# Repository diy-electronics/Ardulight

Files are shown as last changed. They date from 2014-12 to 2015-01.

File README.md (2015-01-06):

Ardulight
=========

Ardu(ino)(Ambi)light: An arduino based ambilight controller for WS2801 based digital rgb led pixels.

Example-Video:<br />
<a href="http://www.youtube.com/watch?feature=player_embedded&v=HK8IQF8XRPc
" target="_blank">Example</a>

Images
------

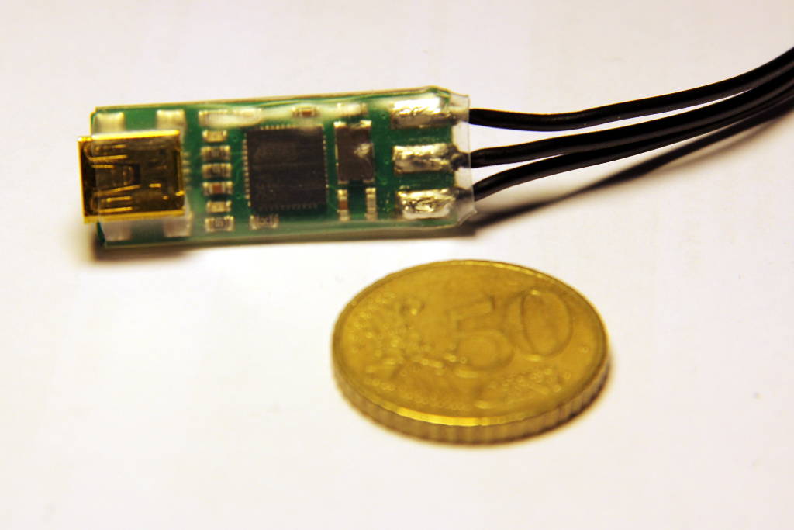
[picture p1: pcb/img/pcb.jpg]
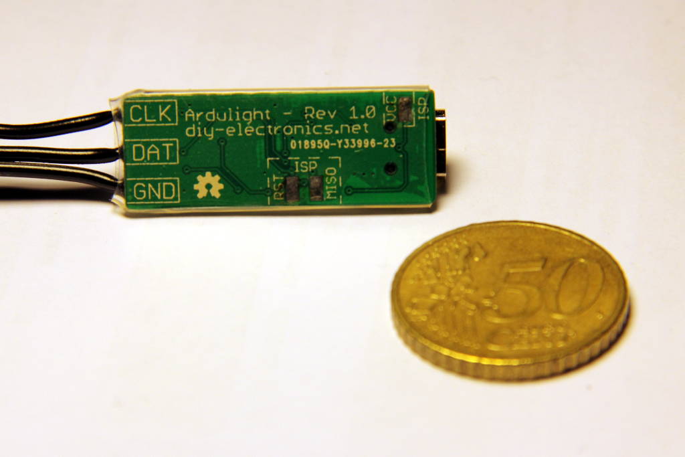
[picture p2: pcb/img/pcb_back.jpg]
&nbsp;&nbsp;&nbsp;

Assembly
--------

Assembly instructions including a BOM (bill of materials) can be found [here](../master/pcb).<br />
The pcb has to be soldered by hot air or by reflow due to the qfp package of the atmega32u4.

Wiring
------

For a detailed wiring guide look [here](https://learn.adafruit.com/adalight-diy-ambient-tv-lighting/wiring-1).<br />
The LED-Strip has to be powered from an external power source, using e.g. a connector like [this](https://www.adafruit.com/products/368).<br />
You only have to connect GND, CLK (SCK) and DAT (MOSI).  

Firmware
--------

The firmware can be found [here](../master/firmware/firmware.pde)<br />
You can flash this firmware using an isp-programmer.<br />
Alternatively you can first flash the arduino leonardo bootloader with an isp-programmer and then flash the firmware directly over usb since the ambilight controller is compatible with the arduino leonardo.

Software
--------

The ambilight controller works with [Prismatik from woodenshark](https://github.com/woodenshark/Lightpack/releases/latest) (Alternative download [here](http://lightpack.tv/downloads)).

To fix the systems device name and permissions for Ardulight on linux systems, you can add [the udev rule](98-ardulight.rules) to `/etc/udev/rules.d/`. The device name is then `/dev/ttyARDULIGHT` and is owned by `users (mode 0666)`.

License
-------

<br />This work is licensed under a <a rel="license" href="http://creativecommons.org/licenses/by-sa/4.0/">Creative Commons Attribution-ShareAlike 4.0 International License</a>.<br />
The firmware is licensed under a GNU Lesser General Public, see <http://www.gnu.org/licenses/>.<br />

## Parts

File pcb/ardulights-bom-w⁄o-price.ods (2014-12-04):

Qty | Value | Package | Parts | Description | Distributor/PN
1 |  | QFN-44 | U1 | IC MCU 8BIT 32KB FLASH 44QFN | Digikey: ATMEGA32U4-MU-ND
1 |  | SMD | JP1 | CONN MINI USB RCPT RA TYPE B SMD | Digikey: 151-1206-1-ND
1 | 16M | SMD | Y1 | CRYSTAL 16MHZ 8PF SMD | Digikey: 644-1194-1-ND
2 | 18p | 0603 | C5, C6 | CAP CER 18PF 50V 5% C0G 0603 | Digikey: 445-1272-1-ND
3 | 0.1u | 0603 | C1, C2, C3 | CAP CER 0.1UF 25V 10% X7R 0603 | Digikey: 445-1316-1-ND
1 | 10k | 0603 | R2 | RES 10K OHM 1/10W 1% 0603 | Digikey: A106048CT-ND
2 | 22R | 0603 | R3, R4 | RES 22 OHM 1/10W 1% 0603 | Digikey: RMCF0603FT22R0CT-ND
1 | 1u | 0603 | C4 | CAP CER 1UF 50V 10% X5R 0603 | Digikey: 445-7468-1-ND
1 | BLUE | 0603 | PWR | LED 468NM BLUE CLEAR 0603 SMD | Digikey: 160-1647-1-ND
1 | YELLOW | 0603 | RX | LED YELLOW CLEAR THIN 0603 SMD | Digikey: 160-1448-1-ND
1 | 150R | 0603 | R5 | RES 150 OHM 1/10W 1% 0603 SMD | Digikey: RHM150CFCT-ND
1 | 82R | 0603 | R1 | RES 82 OHM 1/10W 1% 0603 SMD | Digikey: RHM82CFCT-ND
---- optional ----
1 |  |  |  | CBL USB A-MNI B CON 3' 28/28 AWG | Digikey: Q362-ND
1 |  |  |  | 4-pin JST SM Plug + Receptacle Cable Set | EXP-TECH: EXP-R15-235
1 |  |  |  | Female DC Power adapter - 2.1mm jack to screw terminal block | EXP-TECH: EXP-R15-080

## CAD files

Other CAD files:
pcb/ardulight.skp

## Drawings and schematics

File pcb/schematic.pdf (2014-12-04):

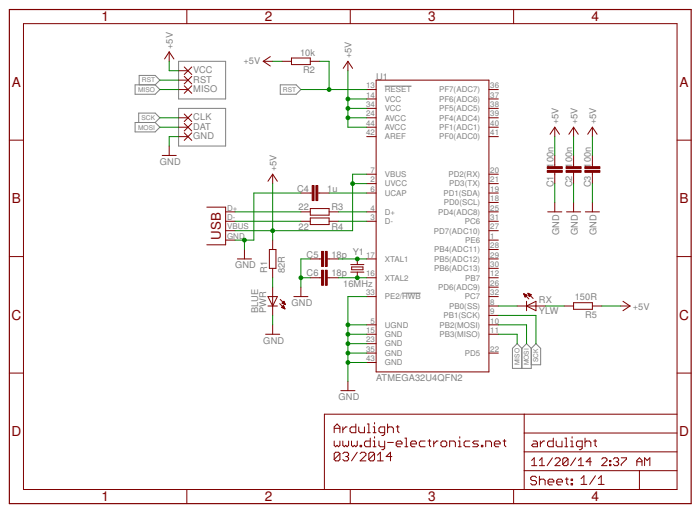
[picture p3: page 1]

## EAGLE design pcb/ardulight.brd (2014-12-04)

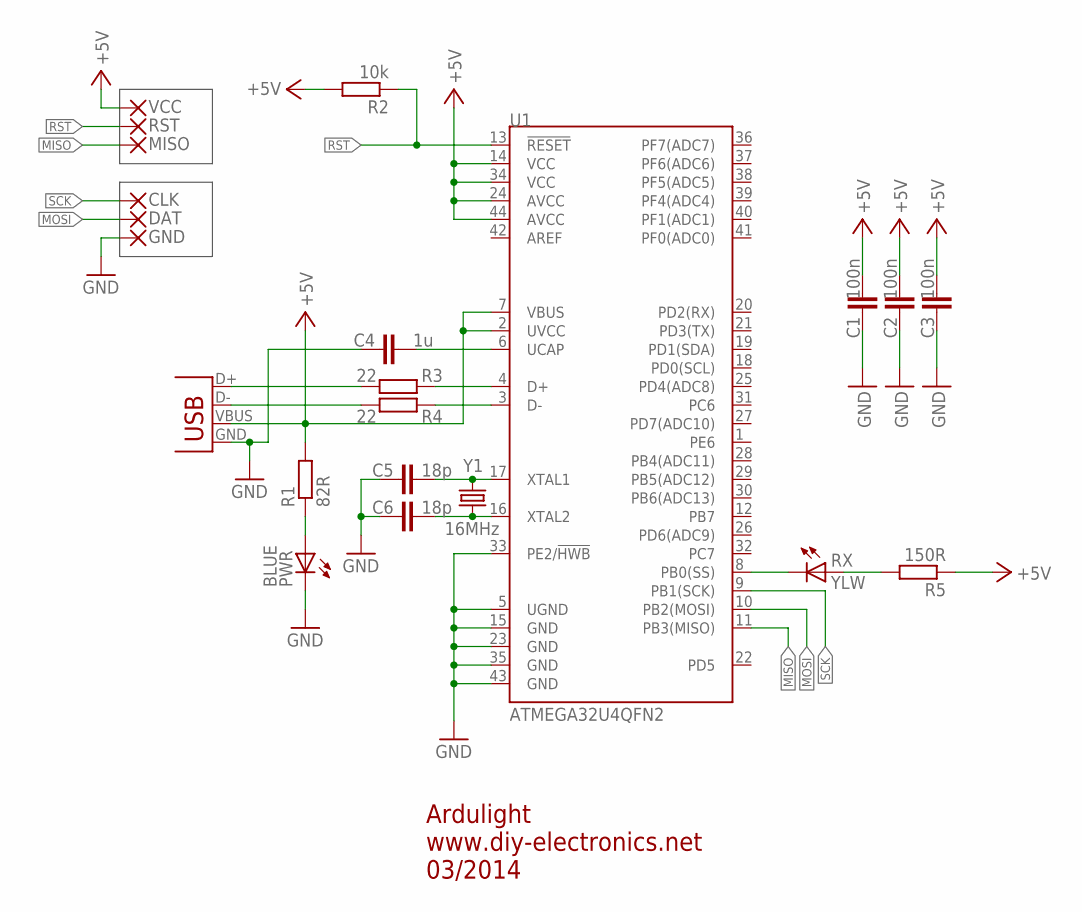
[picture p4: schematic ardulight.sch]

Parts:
C1, C2, C3: 100n; C0603
C4: 1u; C0603
C5, C6: 18p; C0603
CLK: SMD5; SMD2,54-5,08
DAT: SMD5; SMD2,54-5,08
GND: SMD5; SMD2,54-5,08
JP1: USBSMD; USB-MINIB
MISO: SMD2; SMD1,27-2,54
PWR: BLUE; CHIPLED_0603
R1: 82R; R0603
R2: 10k; R0603
R3, R4: 22; R0603
R5: 150R; R0603
RST: SMD2; SMD1,27-2,54
RX: YLW; CHIPLED_0603
U1: ATMEGA32U4QFN2; SPARKFUN-DIGITALIC_QFN-44-NOPAD
VCC: SMD2; SMD1,27-2,54
Y1: 16MHz; CRYSTAL-SMD-5X3

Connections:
+5V: C1.2, C2.2, C3.2, JP1.VBUS, R1.2, R2.2, R5.1, U1.2 (UVCC), U1.7 (VBUS), U1.14 (VCC), U1.24 (AVCC), U1.34 (VCC), U1.44 (AVCC), VCC.1
GND: C1.1, C2.1, C3.1, C4.1, C5.1, C6.1, GND.1, JP1.GND, PWR.C, U1.5 (UGND), U1.15 (GND), U1.23 (GND), U1.33 (PE2/!HWB), U1.35 (GND), U1.43 (GND)
MISO: MISO.1, U1.11 (PB3(MISO))
MOSI: DAT.1, U1.10 (PB2(MOSI))
unnamed: C5.2, U1.17 (XTAL1), Y1.3 (2)
unnamed: C6.2, U1.16 (XTAL2), Y1.1
unnamed: R3.1, U1.4 (D+)
unnamed: C4.2, U1.6 (UCAP)
unnamed: RX.C, U1.8 (PB0(SS))
unnamed: R4.1, U1.3 (D-)
unnamed: JP1.D+, R3.2
unnamed: JP1.D-, R4.2
unnamed: PWR.A, R1.1
unnamed: R5.2, RX.A
RST: R2.1, RST.1, U1.13 (!RESET)
SCK: CLK.1, U1.9 (PB1(SCK))

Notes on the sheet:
Ardulight
www.diy-electronics.net
03/2014

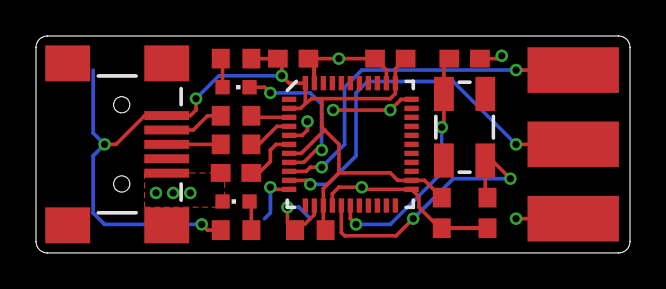
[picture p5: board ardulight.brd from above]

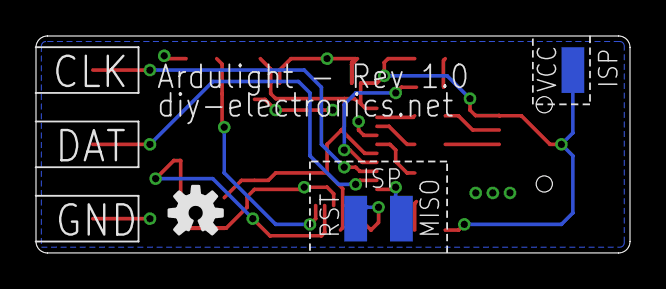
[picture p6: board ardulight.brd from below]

Board: 2 copper layers, 33.0 x 12.1 mm, 23 parts (4 on the bottom side), 16 nets.

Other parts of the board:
U$1: OSHW-LOGO-S

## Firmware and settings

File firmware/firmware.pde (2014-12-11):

//   This file is part of Adalight.

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
#include <SPI.h>

// A 'magic word' (along with LED count & checksum) precedes each block
// of LED data; this assists the microcontroller in syncing up with the
// host-side software and properly issuing the latch (host I/O is
// likely buffered, making usleep() unreliable for latch).  You may see
// an initial glitchy frame or two until the two come into alignment.
// The magic word can be whatever sequence you like, but each character
// should be unique, and frequent pixel values like 0 and 255 are
// avoided -- fewer false positives.  The host software will need to
// generate a compatible header: immediately following the magic word
// are three bytes: a 16-bit count of the number of LEDs (high byte
// first) followed by a simple checksum value (high byte XOR low byte
// XOR 0x55).  LED data follows, 3 bytes per LED, in order R, G, B,
// where 0 = off and 255 = max brightness.

static const uint8_t magic[] = {'A','d','a'};
#define MAGICSIZE  sizeof(magic)
#define HEADERSIZE (MAGICSIZE + 3)

#define MODE_HEADER 0
#define MODE_HOLD   1
#define MODE_DATA   2

// If no serial data is received for a while, the LEDs are shut off
// automatically.  This avoids the annoying "stuck pixel" look when
// quitting LED display programs on the host computer.
static const unsigned long serialTimeout = 15000; // 15 seconds

void setup()
{
  // Dirty trick: the circular buffer for serial data is 256 bytes,
  // and the "in" and "out" indices are unsigned 8-bit types -- this
  // much simplifies the cases where in/out need to "wrap around" the
  // beginning/end of the buffer.  Otherwise there'd be a ton of bit-
  // masking and/or conditional code every time one of these indices
  // needs to change, slowing things down tremendously.
  uint8_t
    buffer[256],
    indexIn       = 0,
    indexOut      = 0,
    mode          = MODE_HEADER,
    hi, lo, chk, i, spiFlag;
  int16_t
    bytesBuffered = 0,
    hold          = 0,
    c;
  int32_t
    bytesRemaining;
  unsigned long
    startTime,
    lastByteTime,
    lastAckTime,
    t;

  Serial.begin(115200); // Teensy/32u4 disregards baud rate; is OK!

  SPI.begin();
  SPI.setBitOrder(MSBFIRST);
  SPI.setDataMode(SPI_MODE0);
  SPI.setClockDivider(SPI_CLOCK_DIV16); // 1 MHz max, else flicker

  // Issue test pattern to LEDs on startup.  This helps verify that
  // wiring between the Arduino and LEDs is correct.  Not knowing the
  // actual number of LEDs connected, this sets all of them (well, up
  // to the first 25,000, so as not to be TOO time consuming) to red,
  // green, blue, then off.  Once you're confident everything is working
  // end-to-end, it's OK to comment this out and reprogram the Arduino.
  uint8_t testcolor[] = { 0, 0, 0, 255, 0, 0 };
  for(char n=3; n>=0; n--) {
    for(c=0; c<25000; c++) {
      for(i=0; i<3; i++) {
        for(SPDR = testcolor[n + i]; !(SPSR & _BV(SPIF)); );
      }
    }
    delay(1); // One millisecond pause = latch
  }

  Serial.print("Ada\n"); // Send ACK string to host

  startTime    = micros();
  lastByteTime = lastAckTime = millis();

  // loop() is avoided as even that small bit of function overhead
  // has a measurable impact on this code's overall throughput.

  for(;;) {

    // Implementation is a simple finite-state machine.
    // Regardless of mode, check for serial input each time:
    t = millis();
    if((bytesBuffered < 256) && ((c = Serial.read()) >= 0)) {
      buffer[indexIn++] = c;
      bytesBuffered++;
      lastByteTime = lastAckTime = t; // Reset timeout counters
    } else {
      // No data received.  If this persists, send an ACK packet
      // to host once every second to alert it to our presence.
      if((t - lastAckTime) > 1000) {
        Serial.print("Ada\n"); // Send ACK string to host
        lastAckTime = t; // Reset counter
      }
      // If no data received for an extended time, turn off all LEDs.
      if((t - lastByteTime) > serialTimeout) {
        for(c=0; c<32767; c++) {
          for(SPDR=0; !(SPSR & _BV(SPIF)); );
        }
        delay(1); // One millisecond pause = latch
        lastByteTime = t; // Reset counter
      }
    }

    switch(mode) {

     case MODE_HEADER:

      // In header-seeking mode.  Is there enough data to check?
      if(bytesBuffered >= HEADERSIZE) {
        // Indeed.  Check for a 'magic word' match.
        for(i=0; (i<MAGICSIZE) && (buffer[indexOut++] == magic[i++]););
        if(i == MAGICSIZE) {
          // Magic word matches.  Now how about the checksum?
          hi  = buffer[indexOut++];
          lo  = buffer[indexOut++];
          chk = buffer[indexOut++];
          if(chk == (hi ^ lo ^ 0x55)) {
            // Checksum looks valid.  Get 16-bit LED count, add 1
            // (# LEDs is always > 0) and multiply by 3 for R,G,B.
            bytesRemaining = 3L * (256L * (long)hi + (long)lo + 1L);
            bytesBuffered -= 3;
            spiFlag        = 0;         // No data out yet
            mode           = MODE_HOLD; // Proceed to latch wait mode
          } else {
            // Checksum didn't match; search resumes after magic word.
            indexOut  -= 3; // Rewind
          }
        } // else no header match.  Resume at first mismatched byte.
        bytesBuffered -= i;
      }
      break;

     case MODE_HOLD:

      // Ostensibly "waiting for the latch from the prior frame
      // to complete" mode, but may also revert to this mode when
      // underrun prevention necessitates a delay.

      if((micros() - startTime) < hold) break; // Still holding; keep buffering

      // Latch/delay complete.  Advance to data-issuing mode...
      mode      = MODE_DATA; // ...and fall through (no break):

     case MODE_DATA:

      while(spiFlag && !(SPSR & _BV(SPIF))); // Wait for prior byte
      if(bytesRemaining > 0) {
        if(bytesBuffered > 0) {
          SPDR = buffer[indexOut++];   // Issue next byte
          bytesBuffered--;
          bytesRemaining--;
          spiFlag = 1;
        }
        // If serial buffer is threatening to underrun, start
        // introducing progressively longer pauses to allow more
        // data to arrive (up to a point).
        if((bytesBuffered < 32) && (bytesRemaining > bytesBuffered)) {
          startTime = micros();
          hold      = 100 + (32 - bytesBuffered) * 10;
          mode      = MODE_HOLD;
	}
      } else {
        // End of data -- issue latch:
        startTime  = micros();
        hold       = 1000;        // Latch duration = 1000 uS
        mode       = MODE_HEADER; // Begin next header search
      }
    } // end switch
  } // end for(;;)
}

void loop()
{
  // Not used.  See note in setup() function.
}

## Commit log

2014-03-17 add vcc to isp
    [ardulight.brd, ardulight.sch]
2014-12-04 more information regarding assembly etc
    [ardulight.brd, ardulight.sch, ardulights-bom-w⁄o-price.ods]
2014-12-04 bom now in pdf
    [ardulights-bom-w⁄o-price.ods]
2014-12-11 add firmware to repo, adjust readme
    [ardulight.brd, ardulight.sch, ardulight.skp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]
2014-12-16 add wiring instructions

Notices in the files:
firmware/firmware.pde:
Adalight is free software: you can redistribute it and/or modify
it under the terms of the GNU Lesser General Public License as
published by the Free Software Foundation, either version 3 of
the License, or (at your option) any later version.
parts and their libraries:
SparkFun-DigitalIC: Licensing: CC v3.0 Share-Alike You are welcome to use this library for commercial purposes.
